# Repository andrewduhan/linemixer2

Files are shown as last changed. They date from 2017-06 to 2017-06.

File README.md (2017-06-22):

linemixer2
=================

Simple active line mixer with input buffers.  
All through-hole components. 
Uses OPA2134 for buffers and summing.

Board measures 98.25mm x 59mm

Front and back panels measure 98.25mm x 19mm

The whole thing measures 98mm x 98.25mm

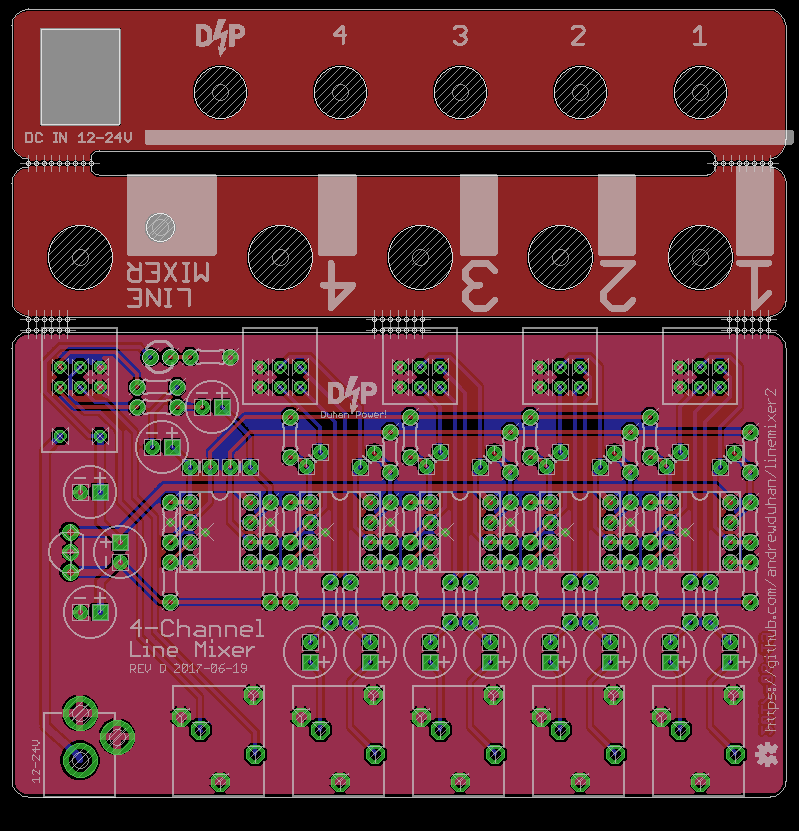
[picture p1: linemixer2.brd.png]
Board


## NOTE: Schematic and board are untested!

## BOM:
* Jacks are Switchcraft 35RAPC4BH3  
* Channel pots are Bourns PTD902-2020K-A103
* Master (switched) pot is Bourns PTR902-2020K-A103
* DC Barrel jack is a standard CUI PJ-202A
* All capacitors are 6.30mm diameter, 2.5mm lead spacing.
* All resistors are the little 3.30mm guys

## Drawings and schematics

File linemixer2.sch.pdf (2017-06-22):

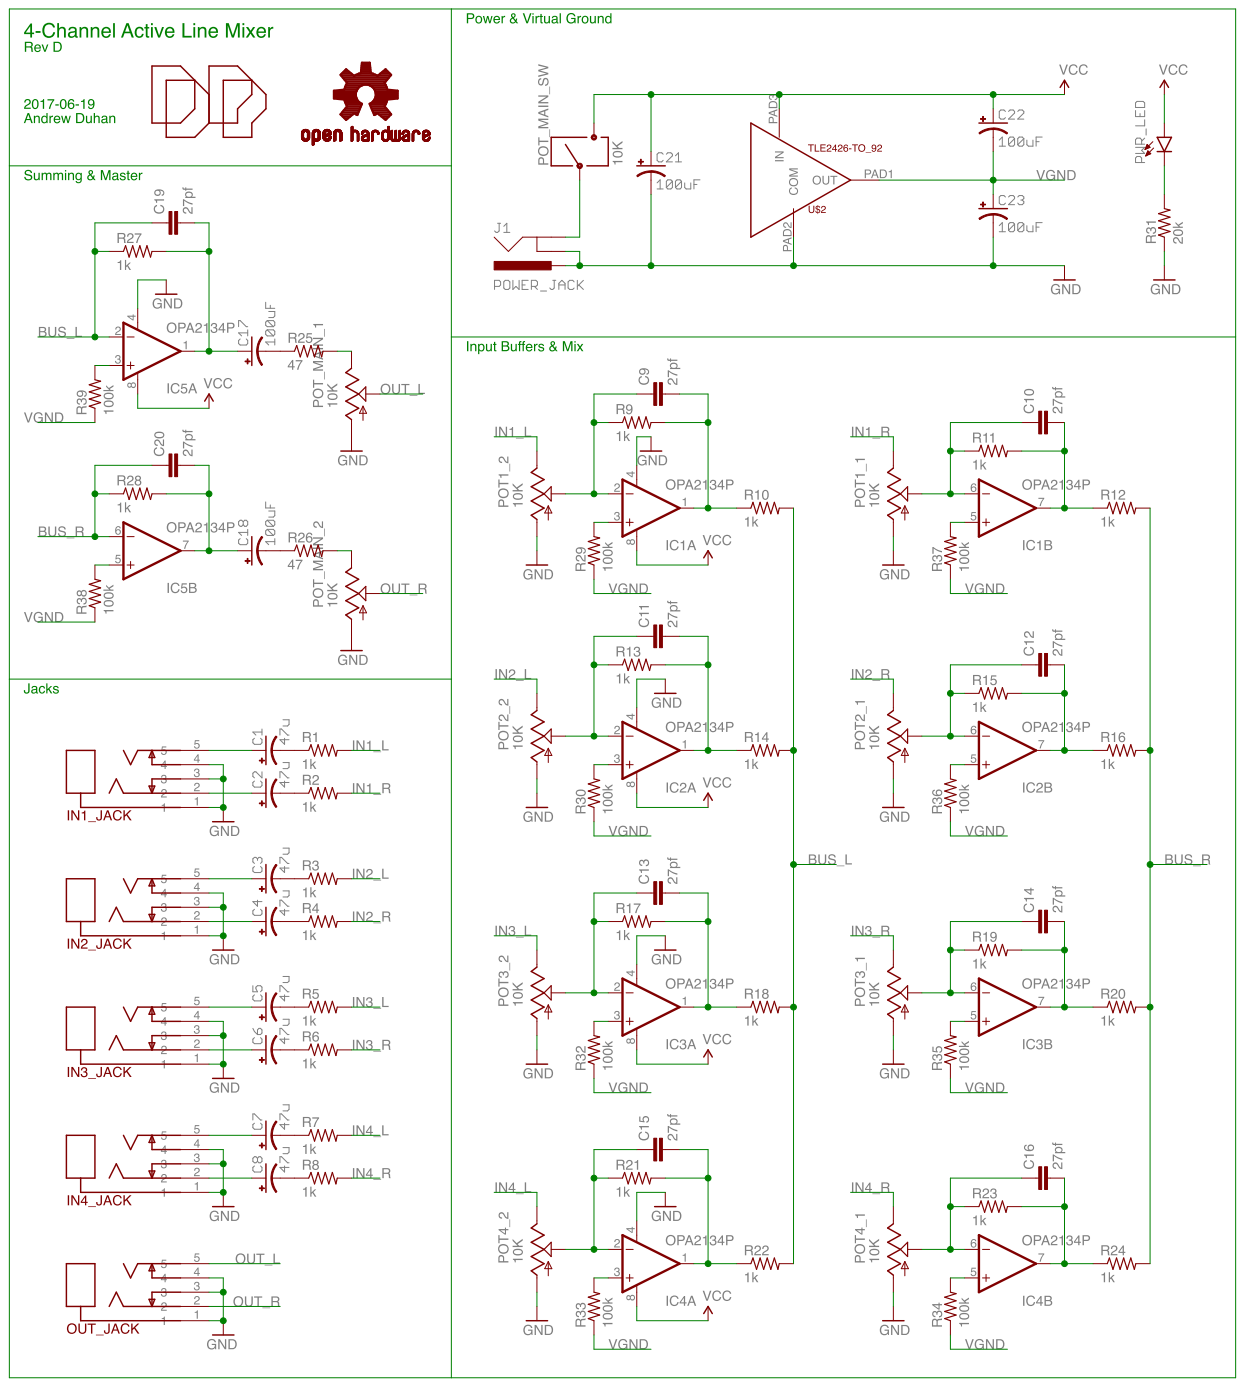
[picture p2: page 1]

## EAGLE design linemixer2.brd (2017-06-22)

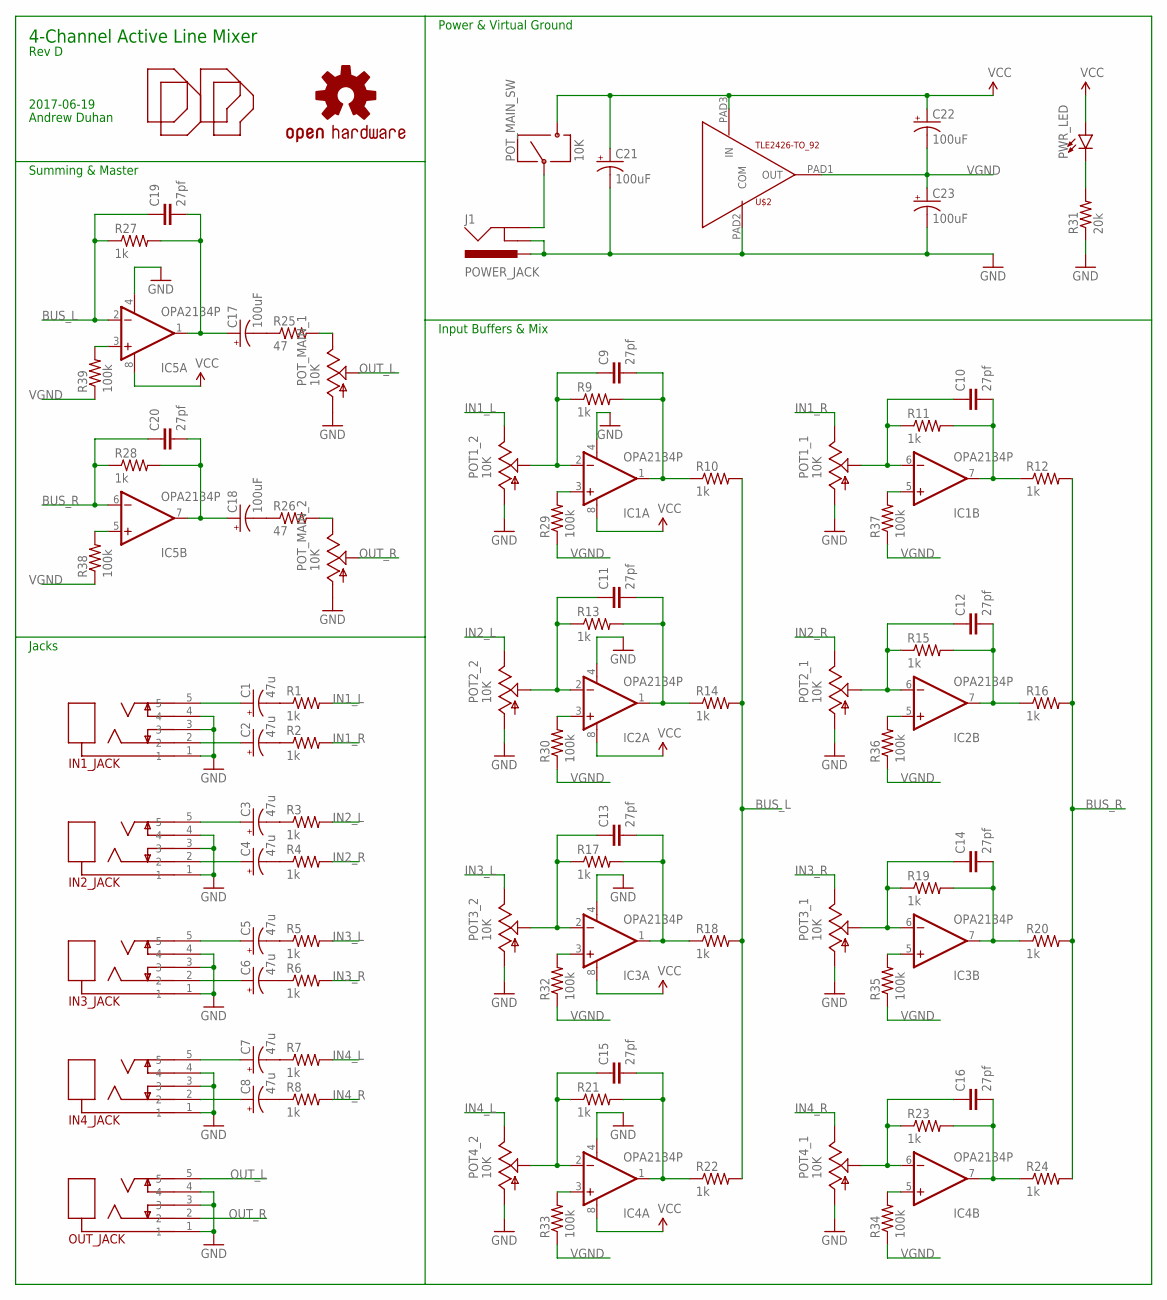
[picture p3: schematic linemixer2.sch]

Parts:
C1, C2, C3, C4, C5, C6, C7, C8: 47u; CPOL-RADIAL-2.5MM-6.5MM
C9, C10, C11, C12, C13, C14, C15, C16, C19, C20: 27pf; CAP-PTH-SMALL
C17, C18, C21, C22, C23: 100uF; CPOL-RADIAL-2.5MM-6.5MM
IC1, IC2, IC3, IC4, IC5: OPA2134P; DIL08
IN1_JACK, IN2_JACK, IN3_JACK, IN4_JACK: JACK_STEREO_SWCUI-SJ1-351X; AUDIO_JACK-CUI-SJ1-351X
J1: POWER_JACK; POWER_JACK_PTH
LOGO1: OSHW-LOGOS; OSHW-LOGO-S
OUT_JACK: JACK_STEREO_SWCUI-SJ1-351X; AUDIO_JACK-CUI-SJ1-351X
POT1_, POT2_, POT3_, POT4_: 10K; BOURNS_PTD902
POT_MAIN_: 10K; BOURNS_PTR902
PWR_LED: LED3MM; LED_3MM
R1, R2, R3, R4, R5, R6, R7, R8, R9, R10, R11, R12, R13, R14, R15, R16, R17, R18, R19, R20, R21, R22, R23, R24, R27, R28: 1k; 0204/5
R25, R26: 47; 0204/5
R29, R30, R32, R33, R34, R35, R36, R37, R38, R39: 100k; 0204/5
R31: 20k; 0204/5
U$1, U$3: DP_LOGO
U$2: TLE2426-TO_92; TO-92

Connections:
BUS_L: C19.1, IC5.2 (-IN), R10.2, R14.2, R18.2, R22.2, R27.1
BUS_R: C20.1, IC5.6 (-IN), R12.2, R16.2, R20.2, R24.2, R28.1
GND: C21.2 (-), C23.2 (-), IC1.4 (V-), IC2.4 (V-), IC3.4 (V-), IC4.4 (V-), IC5.4 (V-), IN1_JACK.1, IN1_JACK.3, IN1_JACK.4, IN2_JACK.1, IN2_JACK.3, IN2_JACK.4, IN3_JACK.1, IN3_JACK.3, IN3_JACK.4, IN4_JACK.1, IN4_JACK.3, IN4_JACK.4, J1.GNDBREAK, J1.PWR, OUT_JACK.1, OUT_JACK.3, OUT_JACK.4, POT1_.R1-A (A), POT1_.R2-A (A), POT2_.R1-A (A), POT2_.R2-A (A), POT3_.R1-A (A), POT3_.R2-A (A), POT4_.R1-A (A), POT4_.R2-A (A), POT_MAIN_.R1-A (A), POT_MAIN_.R2-A (A), R31.1, U$2.PAD2 (COM)
IN1_L: POT1_.R2-B (B), R1.2
IN1_R: POT1_.R1-B (B), R2.2
IN2_L: POT2_.R2-B (B), R3.2
IN2_R: POT2_.R1-B (B), R4.2
IN3_L: POT3_.R2-B (B), R5.2
IN3_R: POT3_.R1-B (B), R6.2
IN4_L: POT4_.R2-B (B), R7.2
IN4_R: POT4_.R1-B (B), R8.2
unnamed: C1.1 (+), IN1_JACK.5
unnamed: C2.1 (+), IN1_JACK.2
unnamed: C3.1 (+), IN2_JACK.5
unnamed: C4.1 (+), IN2_JACK.2
unnamed: C5.1 (+), IN3_JACK.5
unnamed: C6.1 (+), IN3_JACK.2
unnamed: C7.1 (+), IN4_JACK.5
unnamed: C8.1 (+), IN4_JACK.2
unnamed: C1.2 (-), R1.1
unnamed: C2.2 (-), R2.1
unnamed: C3.2 (-), R3.1
unnamed: C4.2 (-), R4.1
unnamed: C5.2 (-), R5.1
unnamed: C6.2 (-), R6.1
unnamed: C7.2 (-), R7.1
unnamed: C8.2 (-), R8.1
unnamed: C9.2, IC1.1 (OUT), R9.2, R10.1
unnamed: C11.2, IC2.1 (OUT), R13.2, R14.1
unnamed: IC1.3 (+IN), R29.2
unnamed: IC5.3 (+IN), R39.2
unnamed: C10.2, IC1.7 (OUT), R11.2, R12.1
unnamed: C17.1 (+), C19.2, IC5.1 (OUT), R27.2
unnamed: C18.1 (+), C20.2, IC5.7 (OUT), R28.2
unnamed: IC5.5 (+IN), R38.2
unnamed: C12.2, IC2.7 (OUT), R15.2, R16.1
unnamed: C13.2, IC3.1 (OUT), R17.2, R18.1
unnamed: C14.2, IC3.7 (OUT), R19.2, R20.1
unnamed: IC2.3 (+IN), R30.2
unnamed: C15.2, IC4.1 (OUT), R21.2, R22.1
unnamed: C16.2, IC4.7 (OUT), R23.2, R24.1
unnamed: IC3.3 (+IN), R32.2
unnamed: C17.2 (-), R25.1
unnamed: C18.2 (-), R26.1
unnamed: POT_MAIN_.R1-B (B), R25.2
unnamed: POT_MAIN_.R2-B (B), R26.2
unnamed: C9.1, IC1.2 (-IN), POT1_.R2-W (W), R9.1
unnamed: PWR_LED.K (C), R31.2
unnamed: J1.GND, POT_MAIN_.P$2 (2)
unnamed: IC4.3 (+IN), R33.2
unnamed: IC4.5 (+IN), R34.2
unnamed: IC3.5 (+IN), R35.2
unnamed: C13.1, IC3.2 (-IN), POT3_.R2-W (W), R17.1
unnamed: C11.1, IC2.2 (-IN), POT2_.R2-W (W), R13.1
unnamed: C15.1, IC4.2 (-IN), POT4_.R2-W (W), R21.1
unnamed: IC2.5 (+IN), R36.2
unnamed: IC1.5 (+IN), R37.2
unnamed: C10.1, IC1.6 (-IN), POT1_.R1-W (W), R11.1
unnamed: C12.1, IC2.6 (-IN), POT2_.R1-W (W), R15.1
unnamed: C14.1, IC3.6 (-IN), POT3_.R1-W (W), R19.1
unnamed: C16.1, IC4.6 (-IN), POT4_.R1-W (W), R23.1
OUT_L: OUT_JACK.5, POT_MAIN_.R1-W (W)
OUT_R: OUT_JACK.2, POT_MAIN_.R2-W (W)
VCC: C21.1 (+), C22.1 (+), IC1.8 (V+), IC2.8 (V+), IC3.8 (V+), IC4.8 (V+), IC5.8 (V+), POT_MAIN_.P$1 (1), PWR_LED.A, U$2.PAD3 (IN)
VGND: C22.2 (-), C23.1 (+), R29.1, R30.1, R32.1, R33.1, R34.1, R35.1, R36.1, R37.1, R38.1, R39.1, U$2.PAD1 (OUT)

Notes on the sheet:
4-Channel Active Line Mixer
Andrew Duhan
Rev D
2017-06-19
Jacks
Summing & Master
Power & Virtual Ground
Input Buffers & Mix

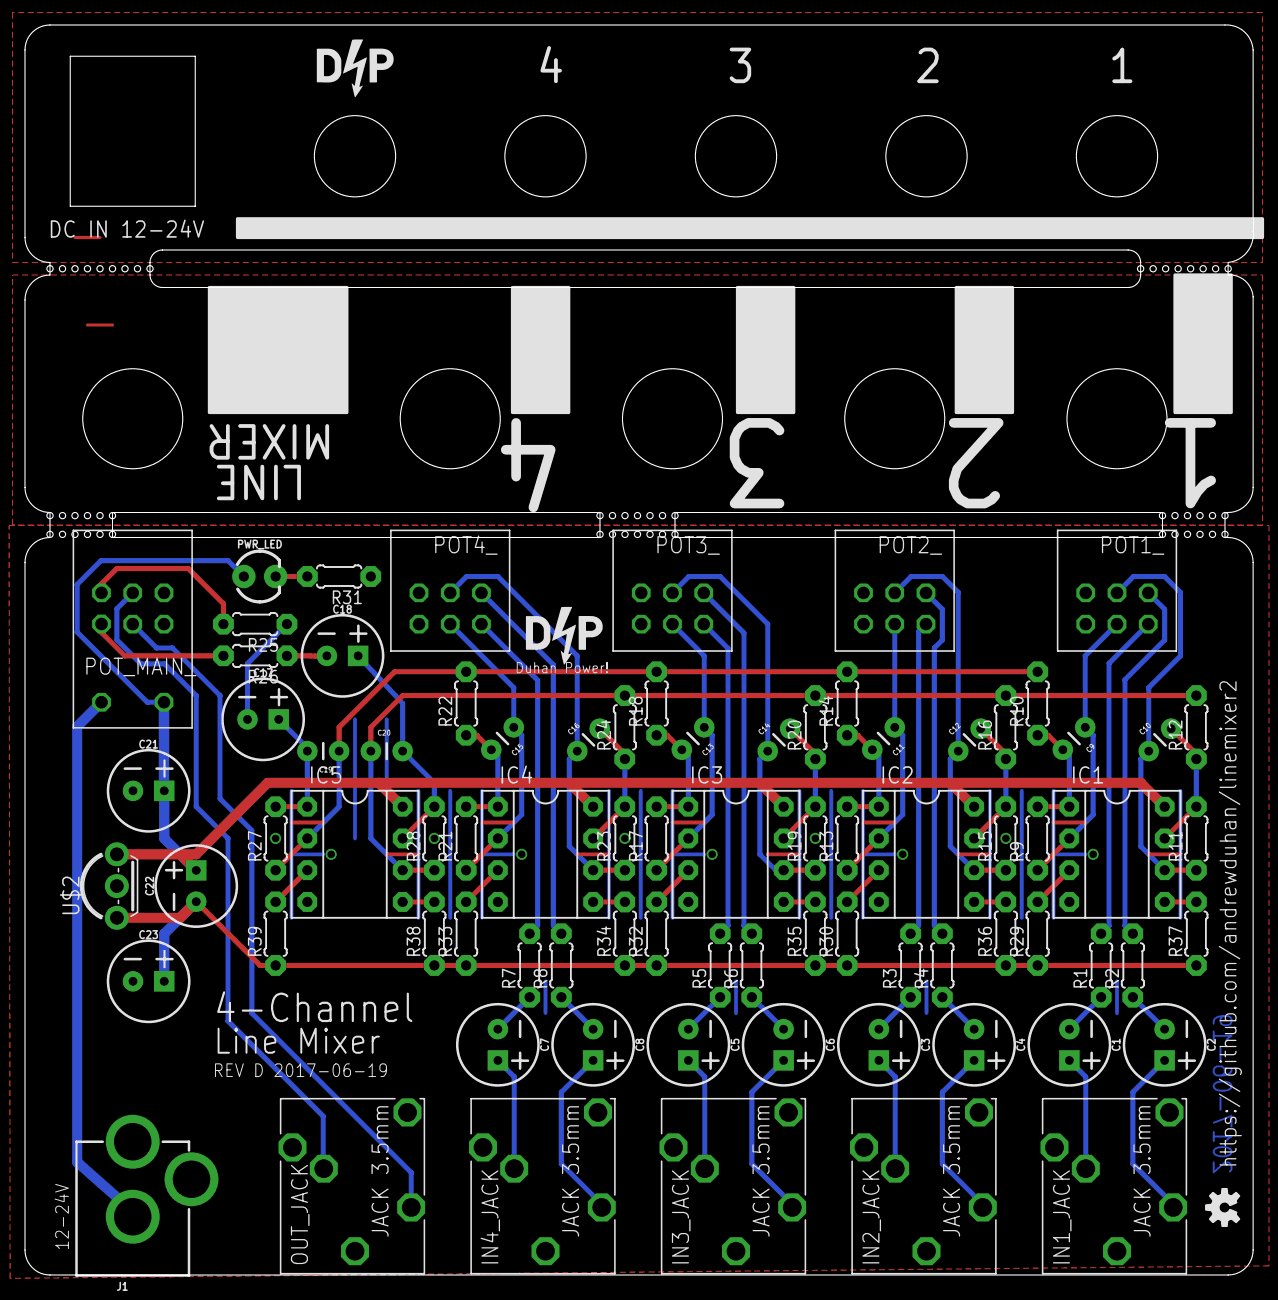
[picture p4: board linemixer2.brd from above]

Board: 2 copper layers, 98.3 x 100.0 mm, 83 parts (0 on the bottom side), 65 nets.

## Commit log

2017-05-30 initial commit, Rev A. Untested.
    [linemixer2.brd, linemixer2.sch]
2017-05-30 board image
2017-05-30 change resistors to 3mm and tweak
    [linemixer2.brd, linemixer2.sch]
2017-06-12 rev b
    [linemixer2.brd, linemixer2.sch]
2017-06-13 rev B tweaks and images
    [linemixer2.brd]
2017-06-13 update board dimensions
2017-06-19 rev c - add resistors to the vgnd on each opamp
    [linemixer2.brd, linemixer2.sch]
2017-06-22 rev D
    [linemixer2.brd, linemixer2.sch]
2017-06-22 readme: update board dimensions

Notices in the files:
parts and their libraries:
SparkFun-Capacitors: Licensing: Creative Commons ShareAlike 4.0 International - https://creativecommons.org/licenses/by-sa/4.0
